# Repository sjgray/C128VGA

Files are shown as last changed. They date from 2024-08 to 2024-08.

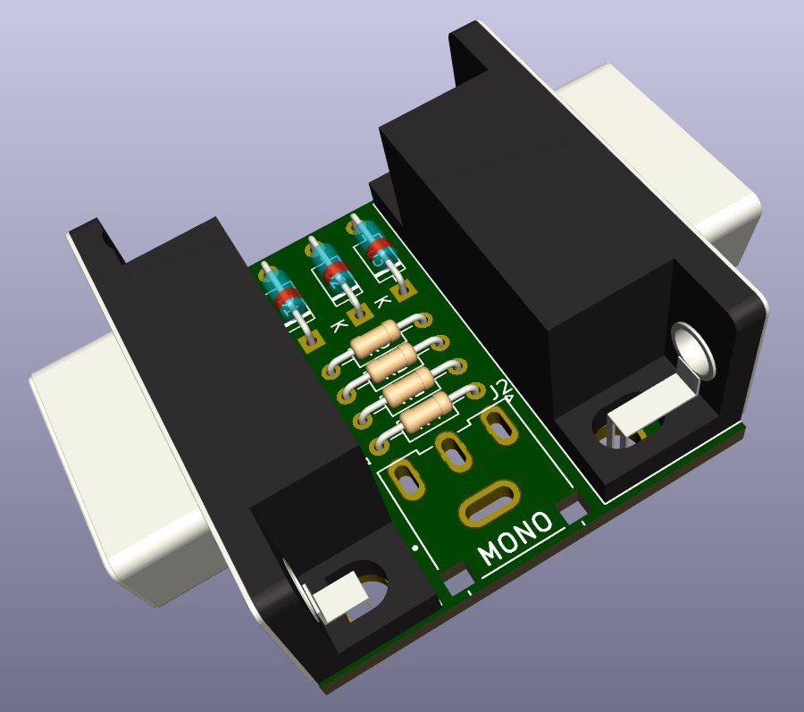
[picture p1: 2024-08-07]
_Pics/c128vga-render-top.jpg

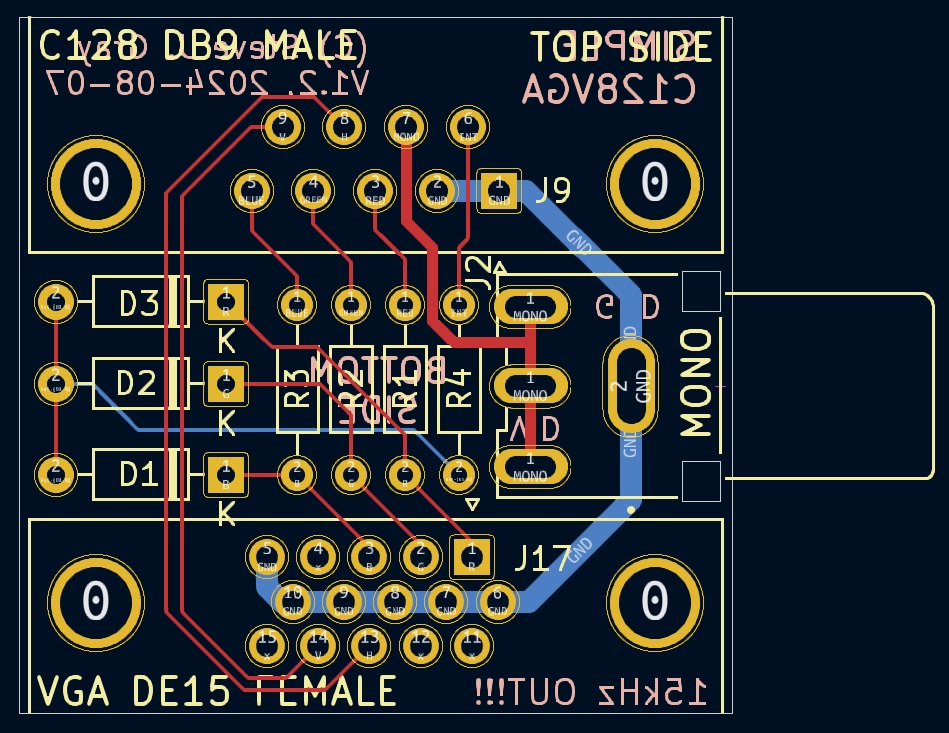
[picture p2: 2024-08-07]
_Pics/c128vga-routed.jpg

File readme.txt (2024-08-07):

Simple C128 to VGA 15kHz Adapter
================================

This is an adapter to convert the C128's 80-column RGBI output
to any VGA monitor that accepts 15kHz scan rate. It uses a
simple RGBI to RGB DAC and does not require any external power.
The adapter also has an RCA connector for Mono composite out.

Project Website
---------------

http://www.cbmsteve.ca/c128vga/index.html

Notes
-----

The DB9 and DE15 pcb-mount connectors both need the hex screws removed in order to connect.
Some cheap connectors will fall apart if the screws are removed. Find ones that are crimped properly.

Gerbers
-------

You can send the ZIP file to most board houses. I use JLCPCB and have had no issues.

History
-------

2024-07-16: V1.0 Prototype PCB with TRS design complete. Gerbers sent to JLCPCB.
2024-07-29: V1.1 Revised PCB with RCA connector complete. Gerbers sent to JLCPCB.
2024-08-07: V1.2 Fixed RCA footprint. Gerbers sent to JLCPCB.
2024-08-07: Webpage created. Uploaded files to GitHub.

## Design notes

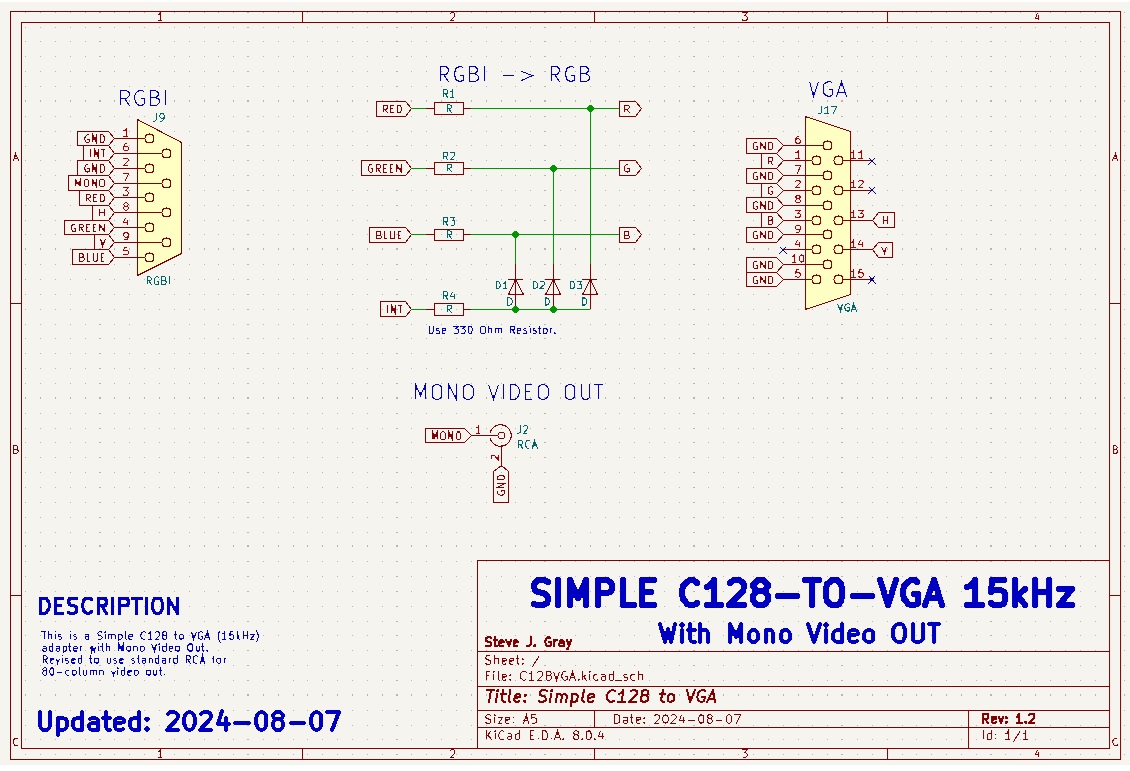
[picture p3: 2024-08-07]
_Pics/c128vga-sch.jpg

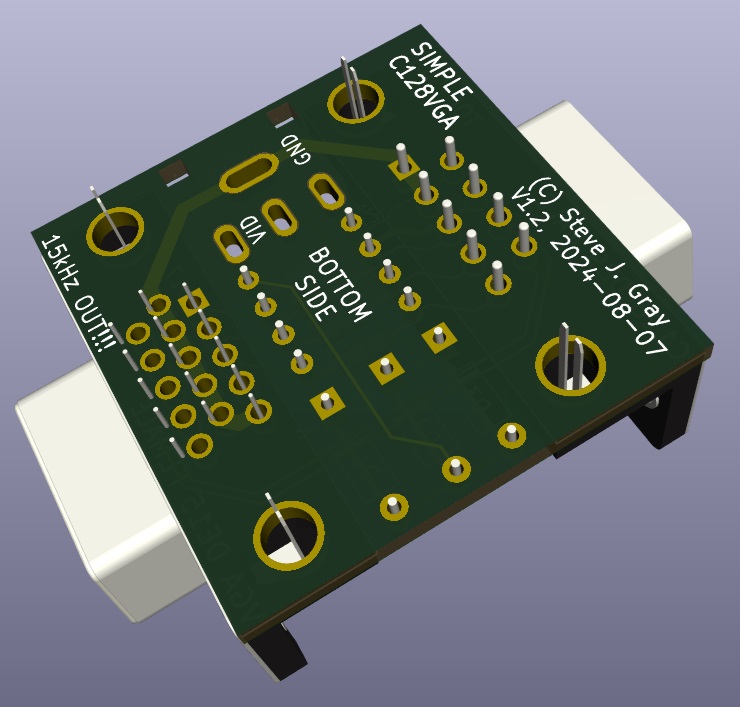
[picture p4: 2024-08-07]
_Pics/c128vga-render-bot.jpg

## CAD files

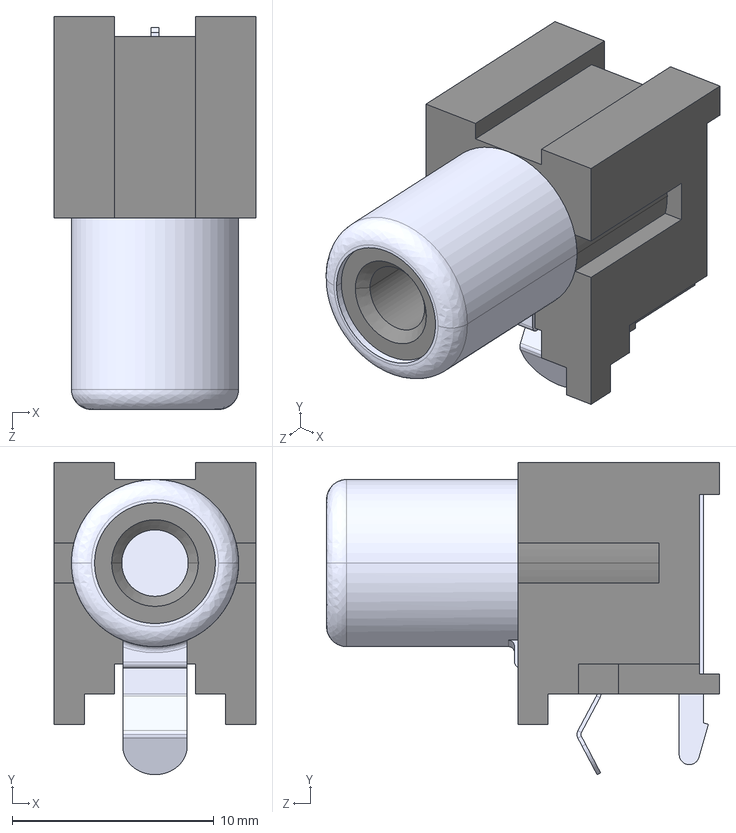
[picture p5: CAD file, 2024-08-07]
_Libs/RCJ-041.step
10.0 x 15.5 x 19.5 mm

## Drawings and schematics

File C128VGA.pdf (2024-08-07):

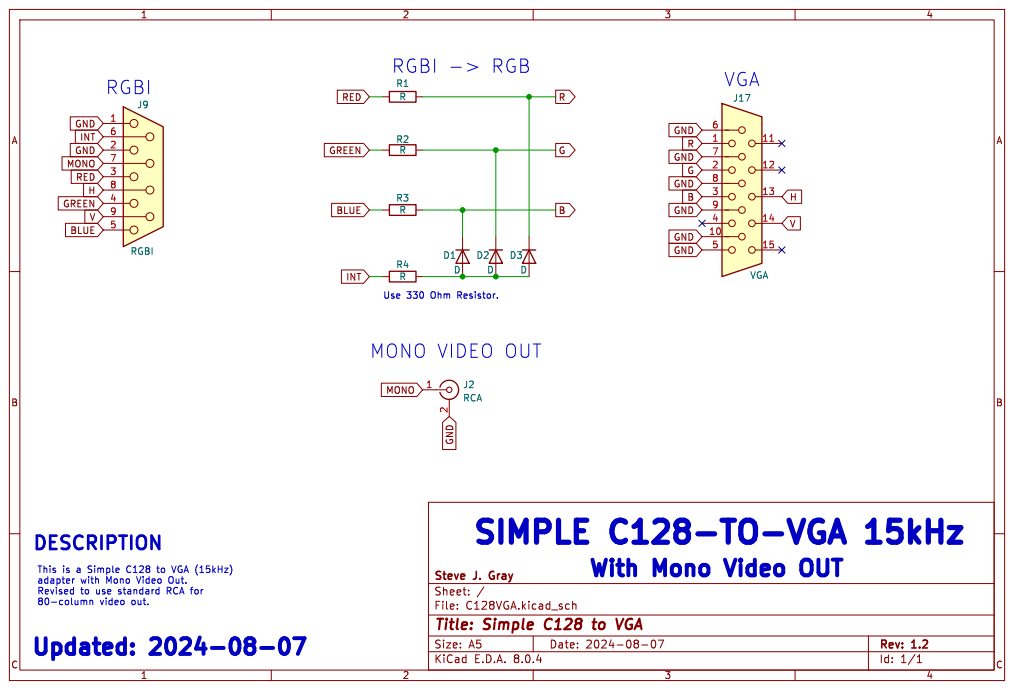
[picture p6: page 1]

File: C128VGA.kicad_sch Sheet: / Steve J. Gray R4R

Id: 1/1 Title: Simple C128 to VGA

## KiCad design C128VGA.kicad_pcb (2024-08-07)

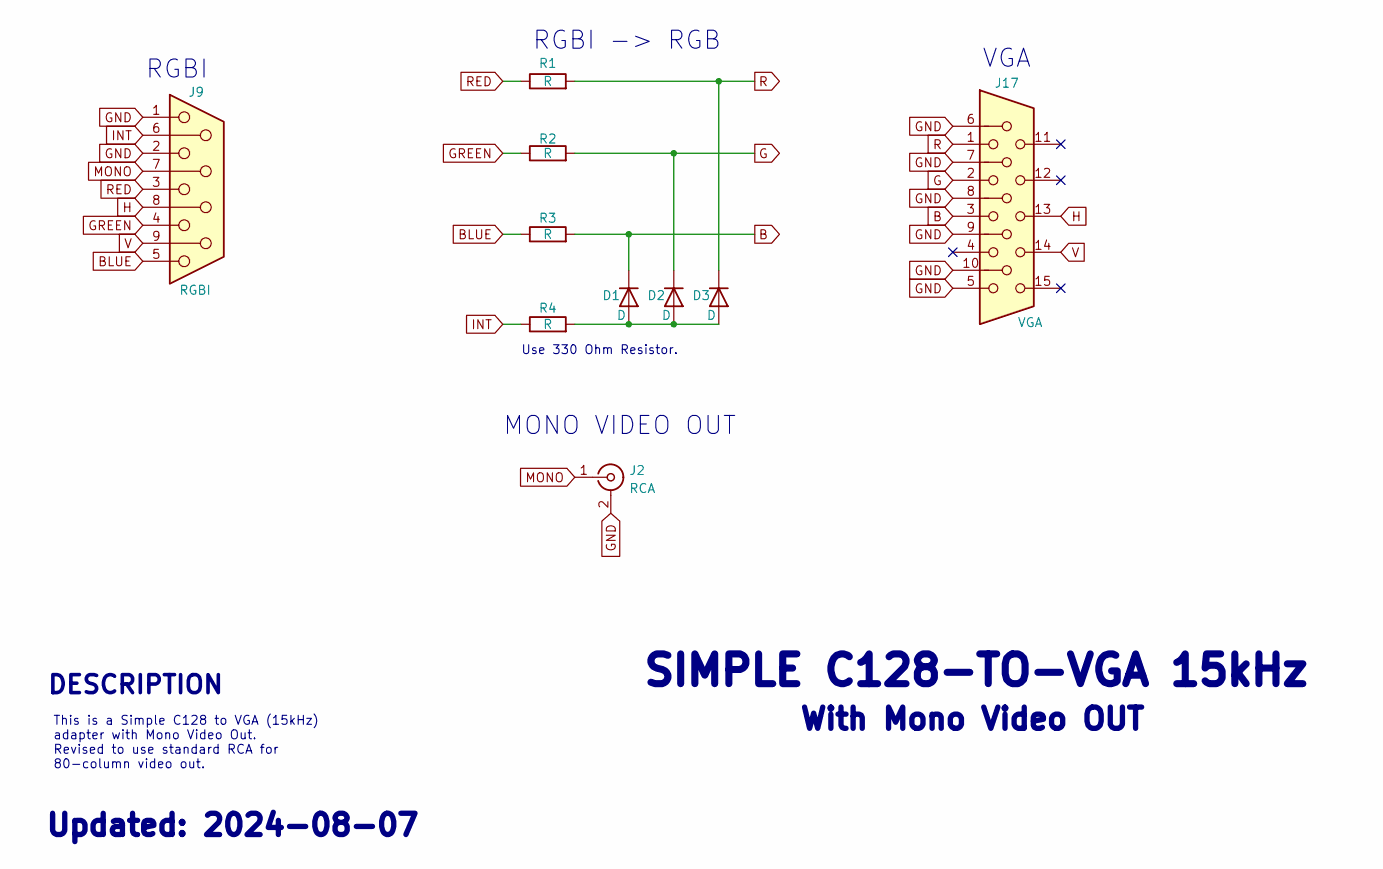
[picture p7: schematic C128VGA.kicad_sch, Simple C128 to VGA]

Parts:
D1, D2, D3: D; D_DO-35_SOD27_P7.62mm_Horizontal
J2: RCA; RCA-custom
J9: RGBI; DSUB-9_Male_Horizontal_P2.77x2.84mm_EdgePinOffset4.94mm_Hou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
J17: VGA; DSUB-15-HD_Female_Horizontal_P2.29x1.98mm_EdgePinOffset3.03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
R1, R2, R3, R4: R; R_Axial_DIN0204_L3.6mm_D1.6mm_P7.62mm_Horizontal

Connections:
B: D1.1 (K), J17.3, R3.2
BLUE: J9.5, R3.1
G: D2.1 (K), J17.2, R2.2
GND: J2.2 (Ext), J9.1, J9.2, J17.5, J17.6, J17.7, J17.8, J17.9, J17.10
GREEN: J9.4, R2.1
H: J9.8, J17.13
INT: J9.6, R4.1
MONO: J2.1 (In), J9.7
unnamed: D1.2 (A), D2.2 (A), D3.2 (A), R4.2
R: D3.1 (K), J17.1, R1.2
RED: J9.3, R1.1
V: J9.9, J17.14

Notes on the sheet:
MONO VIDEO OUT
Updated: 2024-08-07
RGBI
Use 330 Ohm Resistor.
RGBI -> RGB
With Mono Video OUT
DESCRIPTION
VGA
This is a Simple C128 to VGA (15kHz) adapter with Mono Video Out. Revised to use standard RCA for 80-column video out.
SIMPLE C128-TO-VGA 15kHz

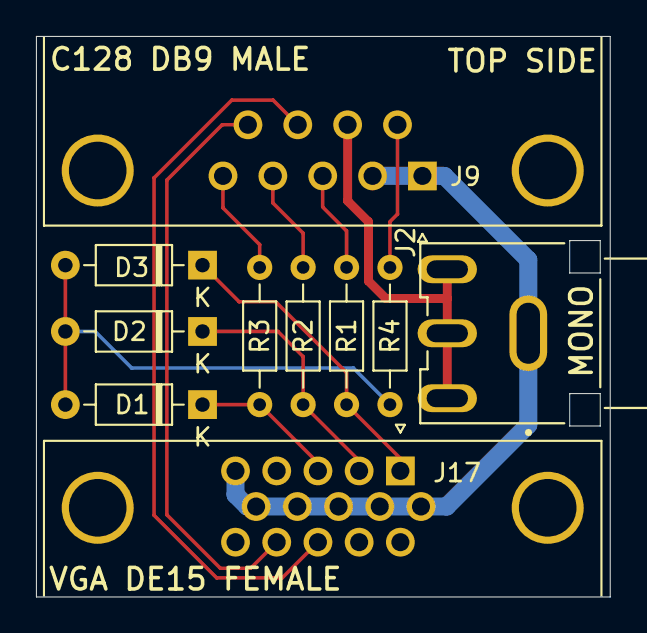
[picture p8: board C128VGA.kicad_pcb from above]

Board: 2 copper layers, 31.9 x 31.1 mm, 10 parts (0 on the bottom side), 12 nets.
